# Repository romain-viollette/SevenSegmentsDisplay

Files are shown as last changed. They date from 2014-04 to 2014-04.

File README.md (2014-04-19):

SevenSegmentsDisplay
====================

description: Autonomous 3 seven-segments display powered by an Atmega328P.

author: Romain VIOLLETTE romain.viollette@gmail.com

https://github.com/romain-viollette/SevenSegmentsDisplay

http://www.oshpark.com/shared_projects/W5Fzhe9d - http://www.oshpark.com/profiles/RomainViollette

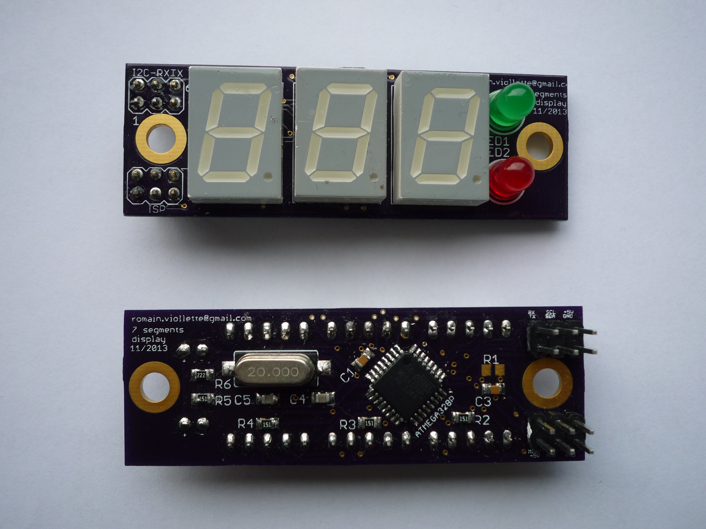
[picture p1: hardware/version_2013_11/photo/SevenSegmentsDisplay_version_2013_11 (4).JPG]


features:
  - small form factor
  - communication: Serial, I2C, SPI, (bitbanging possible if you want to) 
  - SDM components, soldering by hand is not too difficult.
  - 5 volts only
  - Arduino IDE compatible
  - programmable via ISP by default (or maybe via serial lines with a different bootloader)
  - crystal 16Mhz, 20MHz (or whatever or internal if you want to) 
  - 2 support holes for 3 mm screws

partlist: (See complete file in /version_xx/eagle/partlist.txt)
  - PCB at OSHpark.com see http://www.oshpark.com/profiles/RomainViollette
  - 3 x TDSO 5151 - Seven Segments displays with common cathode (any common cathode 7 seg display would fit)
  - 2 leds, any basic ones would fit, adapt R5 and R6 for current limiting.
  - SMD discrete parts form factor 0805:
      - C1 & C3 - 100nF - unpolarized decoupling capacitor
      - C4 & C5 - 12-22pF - unpolarized capacitor for quartz
      - ATMEGA328P-AU - TQFP32 - http://bit.ly/1gV6cmJ
      - QUARTZ - MULTICOMP HC49SM-20-30-50-60-16-ATF - http://bit.ly/1i76kLW
      - R2, R3 & R4 - 150 Ohms - current limiting resistor for 7 seg displays (adapt them to your display specs)
      - R5 & R6 - 150-2200 Ohms  - current limiting resistor for LED (adapt them to your LED specs)
      - R1 - !!!ERROR!!! - do not put anything - R1 could be used as a reset switch (I set R1 as pulldown instead of pullup)
	  
notice:
	- If you beggin in SMD, consider buying http://bit.ly/1ikUmQc and the equivalent for capacitor: you  will save a lot of money at the end.
	- R1 is wrong, see in Partlist.
	- Connectors should be placed on the same side than led display. If you want to put the connector on the other side like I did in the photos (http://bit.ly/1hbSIUK), keep in mind that the pinning is inverted.
	- There is not power regulator, nor overvoltage protection, so nerver power with more than 5V. (Maybe 3.3 could works?).
 
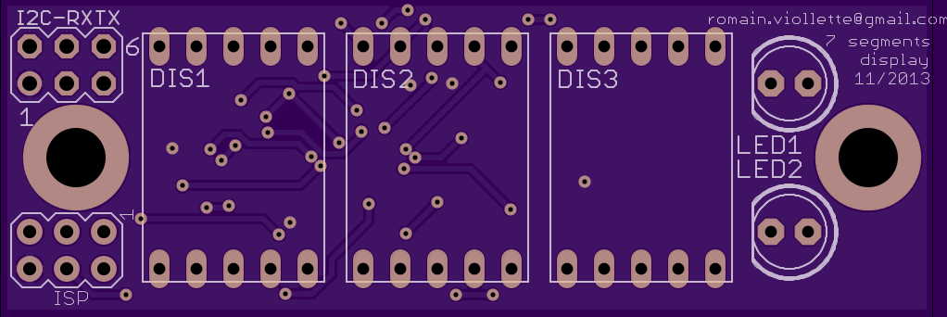
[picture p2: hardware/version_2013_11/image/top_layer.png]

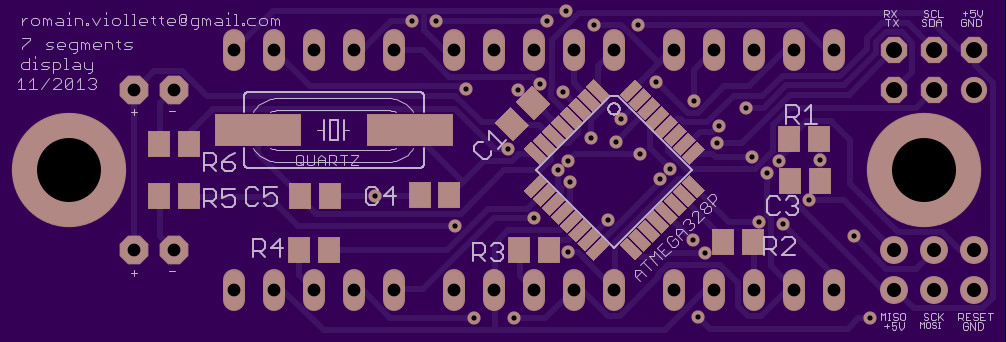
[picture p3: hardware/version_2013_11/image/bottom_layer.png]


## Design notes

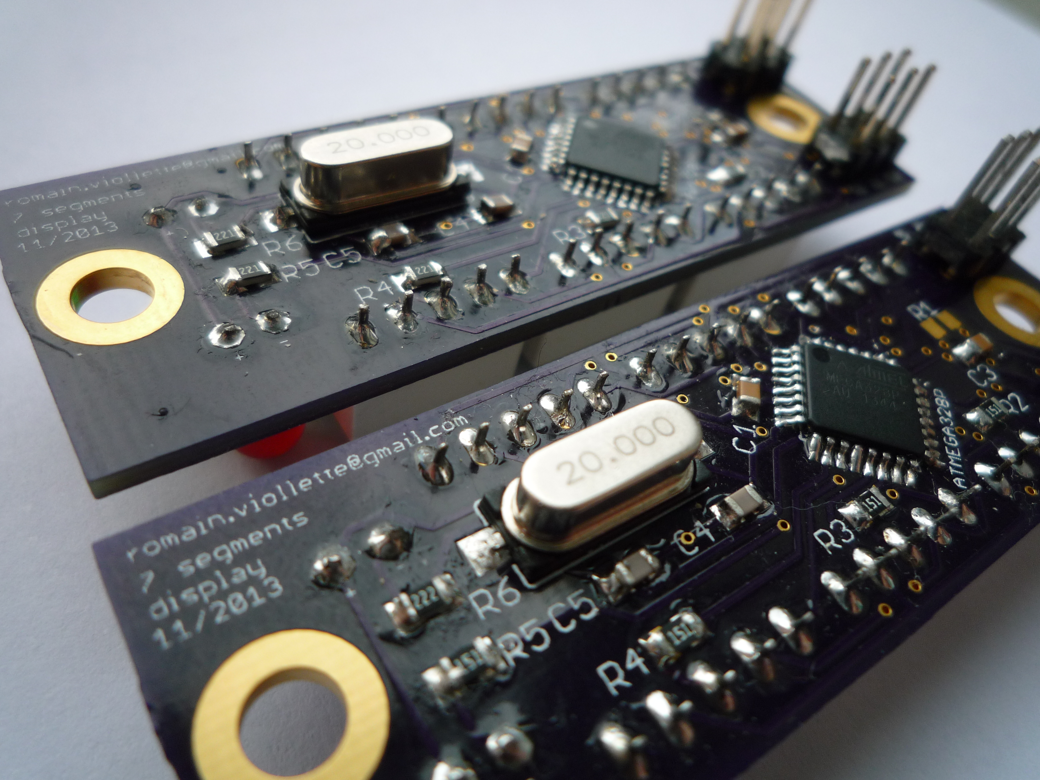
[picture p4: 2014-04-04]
hardware/version_2013_11/photo/SevenSegmentsDisplay_version_2013_11 (9).JPG

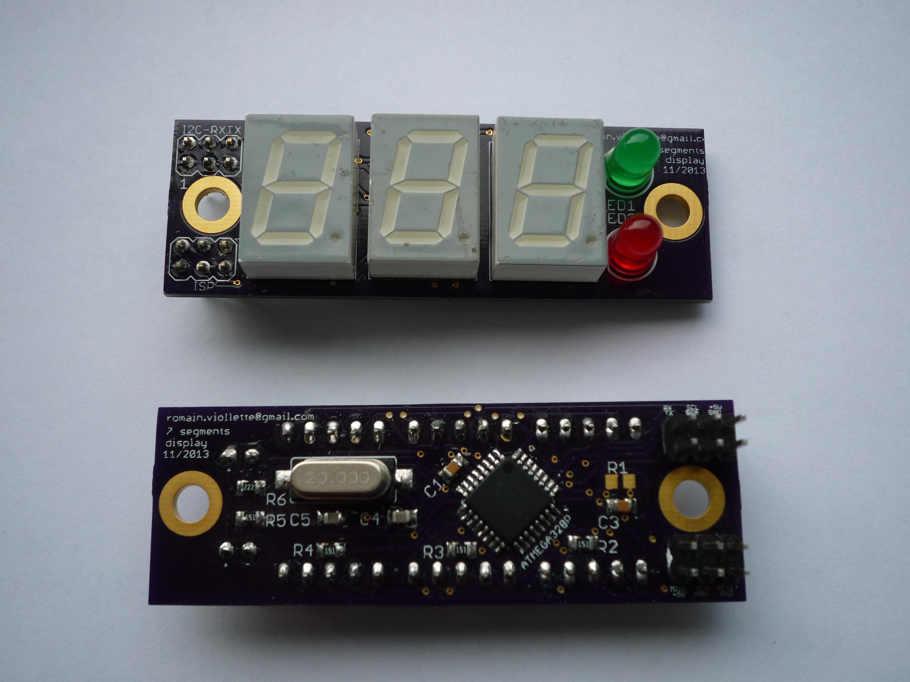
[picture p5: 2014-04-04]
hardware/version_2013_11/photo/SevenSegmentsDisplay_version_2013_11 (5).JPG

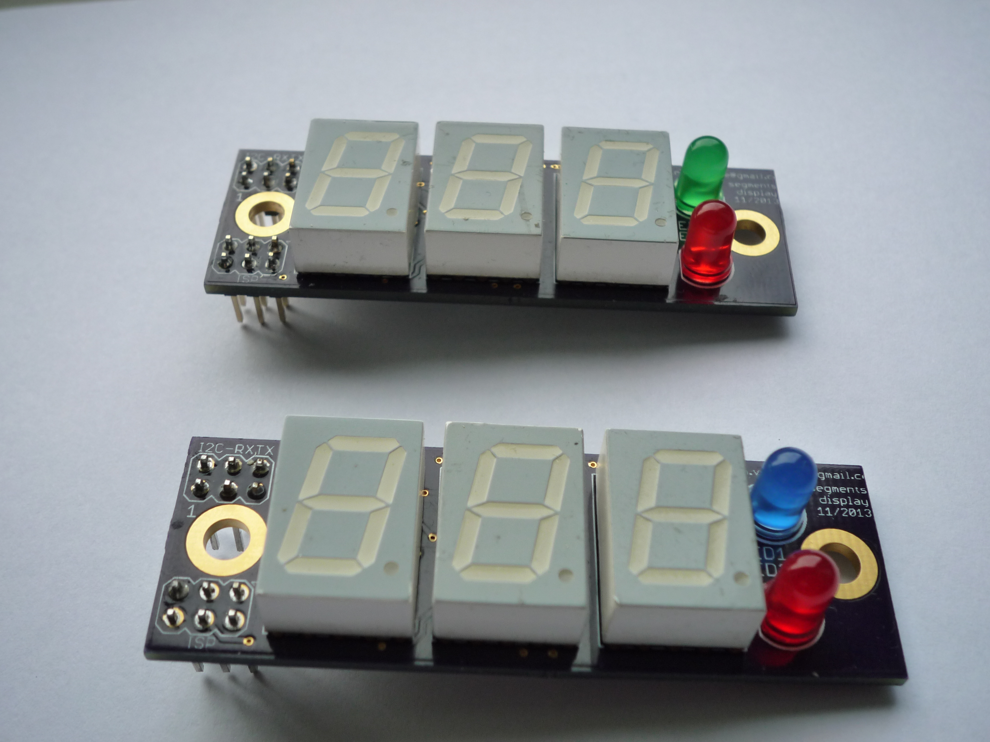
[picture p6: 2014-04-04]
hardware/version_2013_11/photo/SevenSegmentsDisplay_version_2013_11 (3).JPG

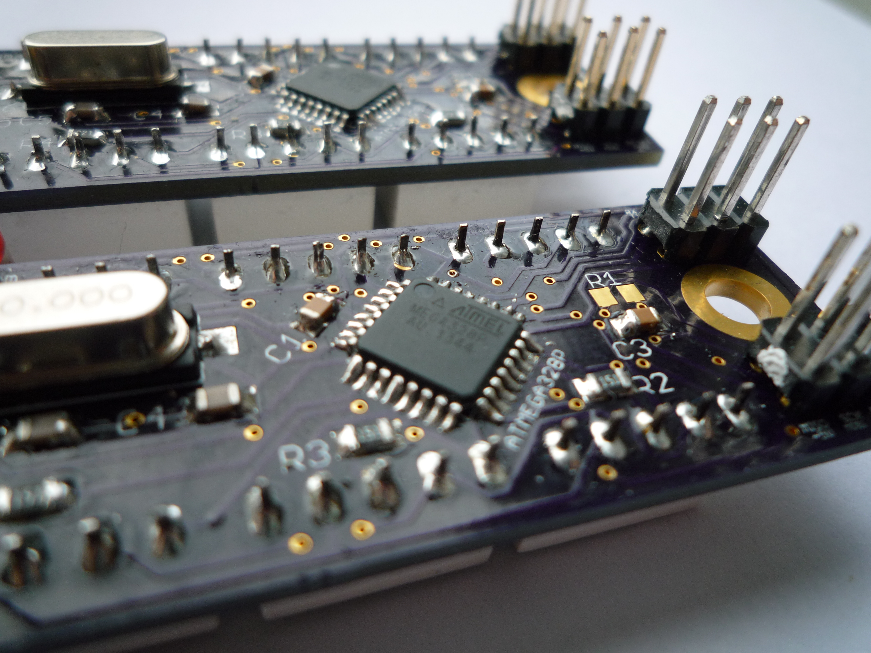
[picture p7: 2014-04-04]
hardware/version_2013_11/photo/SevenSegmentsDisplay_version_2013_11 (7).JPG

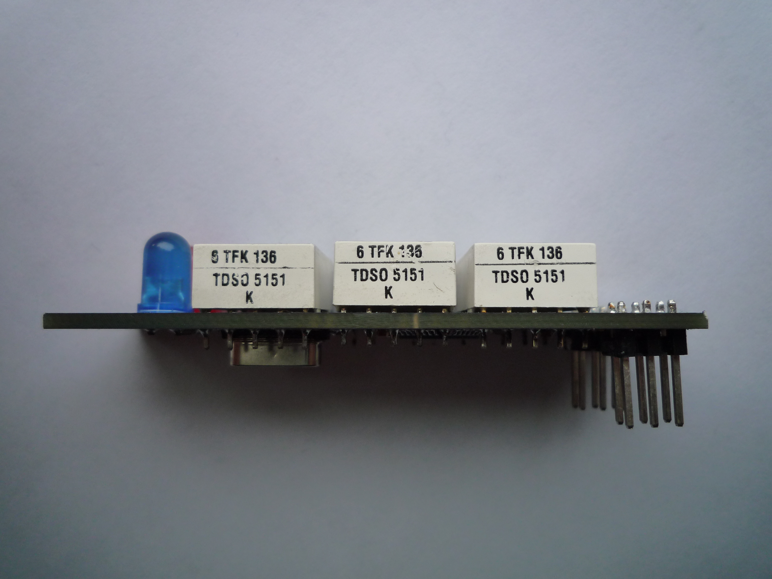
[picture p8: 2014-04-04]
hardware/version_2013_11/photo/SevenSegmentsDisplay_version_2013_11 (1).JPG

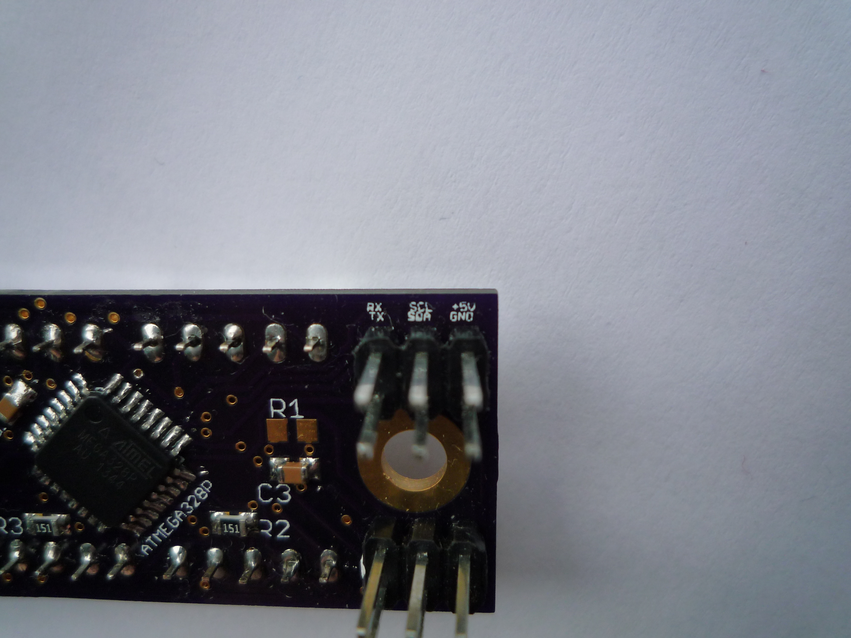
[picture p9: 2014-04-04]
hardware/version_2013_11/photo/SevenSegmentsDisplay_version_2013_11 (11).JPG

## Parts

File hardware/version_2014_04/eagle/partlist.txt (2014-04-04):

Partlist

Exported from interface.brd at 04/04/2014 16:47:50

EAGLE Version 6.1.0 Copyright (c) 1988-2012 CadSoft

Assembly variant: 

Part       Value          Package   Library    Position (inch)       Orientation

ATMEGA328P ATMEGA328P     TQFP32-08 avr-6      (0.98 0.43)           MR315
C1         100nF          C0805     rcl        (1.20992126 0.57173228) MR45
C3         100nF          C0805     rcl        (0.50362205 0.40362205) MR180
C4         12-22pF        C0805     rcl        (1.4288189 0.36661417) MR0
C5         12-22pF        C0805     rcl        (1.7284252 0.36464567) MR180
DIS1                      HDSP-M    display-hp (0.63 0.43)           R0
DIS2                      HDSP-M    display-hp (1.18 0.43)           R0
DIS3                      HDSP-M    display-hp (1.73 0.43)           R0
I2C-RXTX                  MA03-2    con-lstb   (0.18 0.68)           MR0
ISP        AVRISP-6       AVRISP    adafruit   (0.18 0.18)           MR270
LED1                      LED5MM    adafruit   (2.13 0.63)           R180
LED2                      LED5MM    adafruit   (2.13 0.23)           R180
QUARTZ     HC49SM-20      HC49UP    crystal    (1.68 0.53)           MR0
R1         10k            R0805     rcl        (0.50480315 0.50637795) MR180
R2         220            R0805     rcl        (0.67 0.25)           MR180
R3         220            R0805     rcl        (1.18 0.23)           MR0
R4         220            R0805     rcl        (1.73 0.23)           MR0
R5         220            R0805     rcl        (2.08 0.365)          MR180
R6         220            R0805     rcl        (2.08 0.495)          MR180

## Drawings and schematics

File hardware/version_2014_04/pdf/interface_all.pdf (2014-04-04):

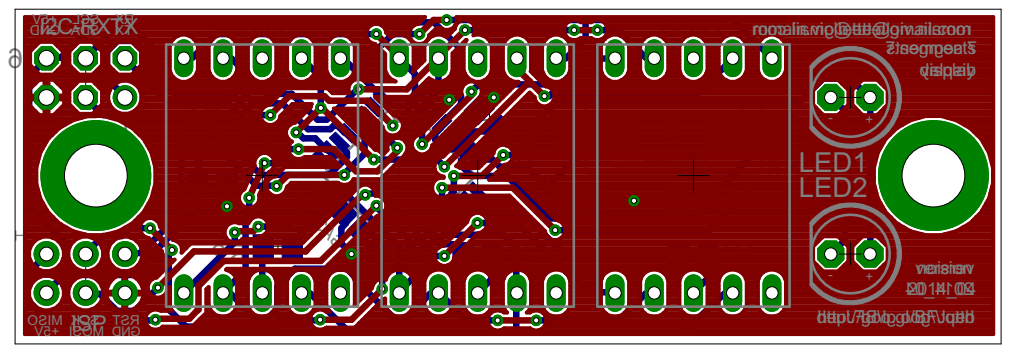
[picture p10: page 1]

3C1R1SI D 2SI D 3SI D ATMEGA328P ZTRAUQ 4C 5C C1 2R 3R 4R 5R6R 1 6I2C-RXTX ISP LED1 LED2 display romain.viollette@gmail.com 7 segments 2014_04 venrosi isornev hbttepu:/J/gFoBo/l.g.l/oBoFg/J/:upettbh 40_4102 yal psi d st ne mges 7 DNG moc.li a mg @ett ell oi v. ni a mor V5+ ADS LCS XTXR DNG TSR I SOM KCS V5+ OSI M + - + -

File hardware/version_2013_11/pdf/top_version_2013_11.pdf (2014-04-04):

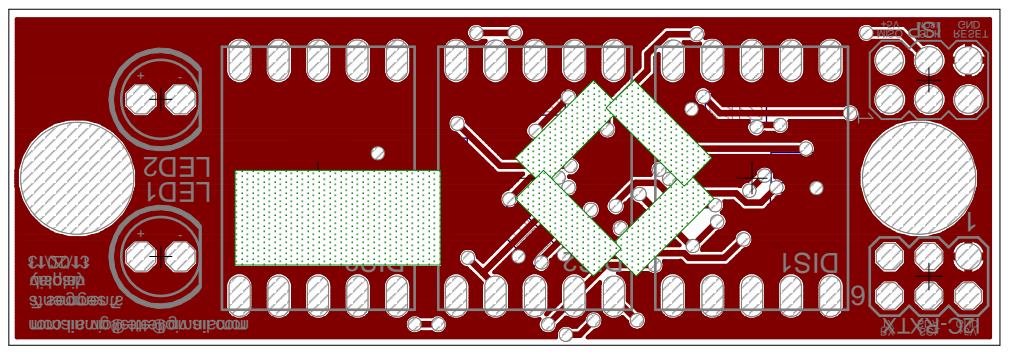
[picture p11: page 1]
11/201311/2013 display 7 segments; romain.viollette@gmail.com; GND; SDA SCL; GND RESET; MOSI SCK; +5V MISO

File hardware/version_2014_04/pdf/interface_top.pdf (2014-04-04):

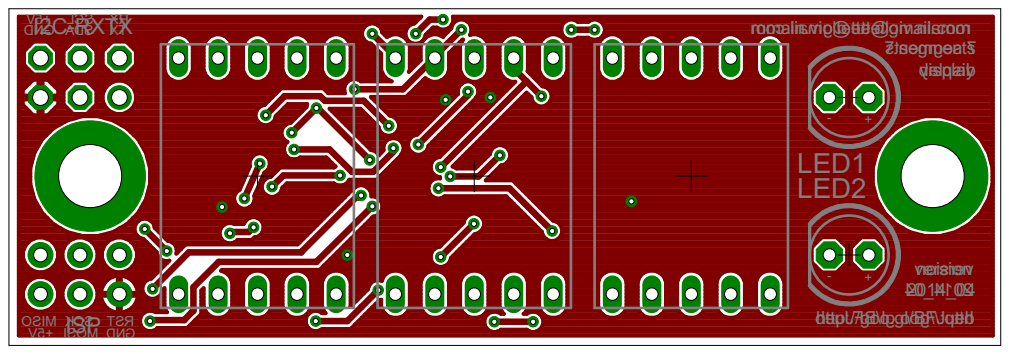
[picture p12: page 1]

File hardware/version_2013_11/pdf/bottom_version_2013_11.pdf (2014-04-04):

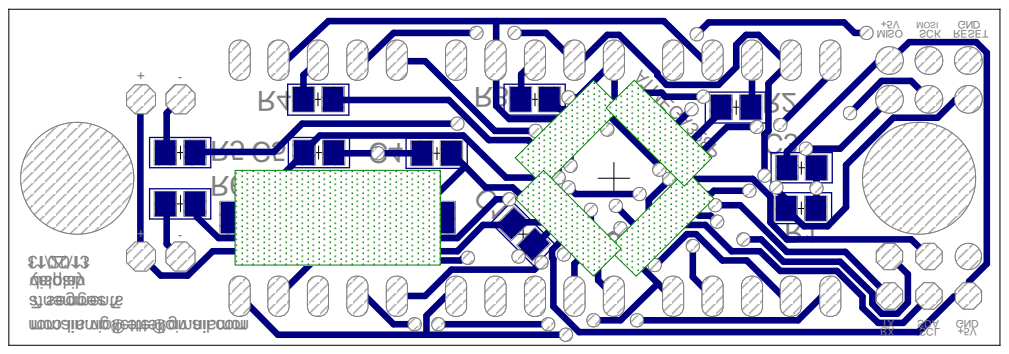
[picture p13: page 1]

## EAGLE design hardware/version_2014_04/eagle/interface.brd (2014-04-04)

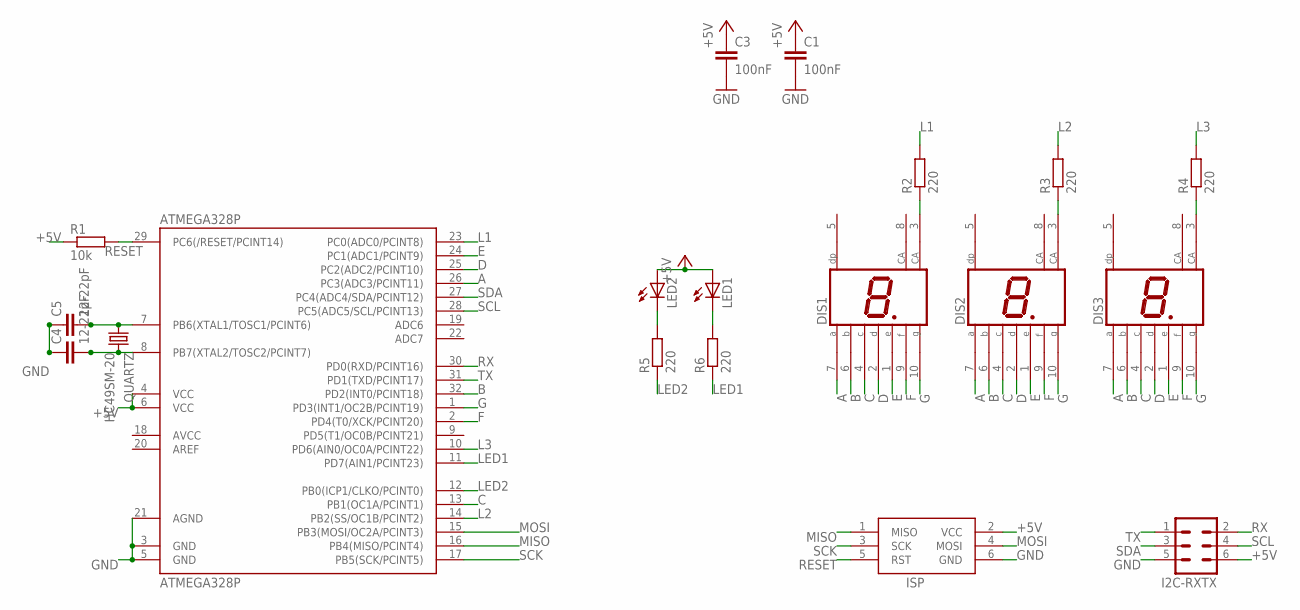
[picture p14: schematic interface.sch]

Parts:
ATMEGA328P: ATMEGA328P; TQFP32-08
C1, C3: 100nF; C0805
C4, C5: 12-22pF; C0805
DIS1, DIS2, DIS3: HD-H101; HDSP-M
I2C-RXTX: MA03-2
ISP: AVRISP-6; AVRISP
LED1, LED2: LED5MM
QUARTZ: HC49SM-20; HC49UP
R1: 10k; R0805
R2, R3, R4, R5, R6: 220; R0805

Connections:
+5V: ATMEGA328P.4 (VCC), ATMEGA328P.6 (VCC), C1.1, C3.1, I2C-RXTX.6, ISP.2 (VCC), LED1.A, LED2.A, R1.1
A: ATMEGA328P.26 (PC3(ADC3/PCINT11)), DIS1.7 (A), DIS2.7 (A), DIS3.7 (A)
B: ATMEGA328P.32 (PD2(INT0/PCINT18)), DIS1.6 (B), DIS2.6 (B), DIS3.6 (B)
C: ATMEGA328P.13 (PB1(OC1A/PCINT1)), DIS1.4 (C), DIS2.4 (C), DIS3.4 (C)
D: ATMEGA328P.25 (PC2(ADC2/PCINT10)), DIS1.2 (D), DIS2.2 (D), DIS3.2 (D)
E: ATMEGA328P.24 (PC1(ADC1/PCINT9)), DIS1.1 (E), DIS2.1 (E), DIS3.1 (E)
F: ATMEGA328P.2 (PD4(T0/XCK/PCINT20)), DIS1.9 (F), DIS2.9 (F), DIS3.9 (F)
G: ATMEGA328P.1 (PD3(INT1/OC2B/PCINT19)), DIS1.10 (G), DIS2.10 (G), DIS3.10 (G)
GND: ATMEGA328P.3 (GND), ATMEGA328P.5 (GND), ATMEGA328P.21 (AGND), C1.2, C3.2, C4.1, C5.1, I2C-RXTX.5, ISP.6 (GND)
L1: ATMEGA328P.23 (PC0(ADC0/PCINT8)), R2.2
L2: ATMEGA328P.14 (PB2(SS/OC1B/PCINT2)), R3.2
L3: ATMEGA328P.10 (PD6(AIN0/OC0A/PCINT22)), R4.2
LED1: ATMEGA328P.11 (PD7(AIN1/PCINT23)), R6.1
LED2: ATMEGA328P.12 (PB0(ICP1/CLKO/PCINT0)), R5.1
MISO: ATMEGA328P.16 (PB4(MISO/PCINT4)), ISP.1 (MISO)
MOSI: ATMEGA328P.15 (PB3(MOSI/OC2A/PCINT3)), ISP.4 (MOSI)
unnamed: ATMEGA328P.8 (PB7(XTAL2/TOSC2/PCINT7)), C4.2, QUARTZ.2
unnamed: ATMEGA328P.7 (PB6(XTAL1/TOSC1/PCINT6)), C5.2, QUARTZ.1
unnamed: DIS2.3 (CA), R3.1
unnamed: DIS3.3 (CA), R4.1
unnamed: LED2.K (C), R5.2
unnamed: DIS1.3 (CA), R2.1
unnamed: LED1.K (C), R6.2
RESET: ATMEGA328P.29 (PC6(/RESET/PCINT14)), ISP.5 (RST), R1.2
RX: ATMEGA328P.30 (PD0(RXD/PCINT16)), I2C-RXTX.2
SCK: ATMEGA328P.17 (PB5(SCK/PCINT5)), ISP.3 (SCK)
SCL: ATMEGA328P.28 (PC5(ADC5/SCL/PCINT13)), I2C-RXTX.4
SDA: ATMEGA328P.27 (PC4(ADC4/SDA/PCINT12)), I2C-RXTX.3
TX: ATMEGA328P.31 (PD1(TXD/PCINT17)), I2C-RXTX.1

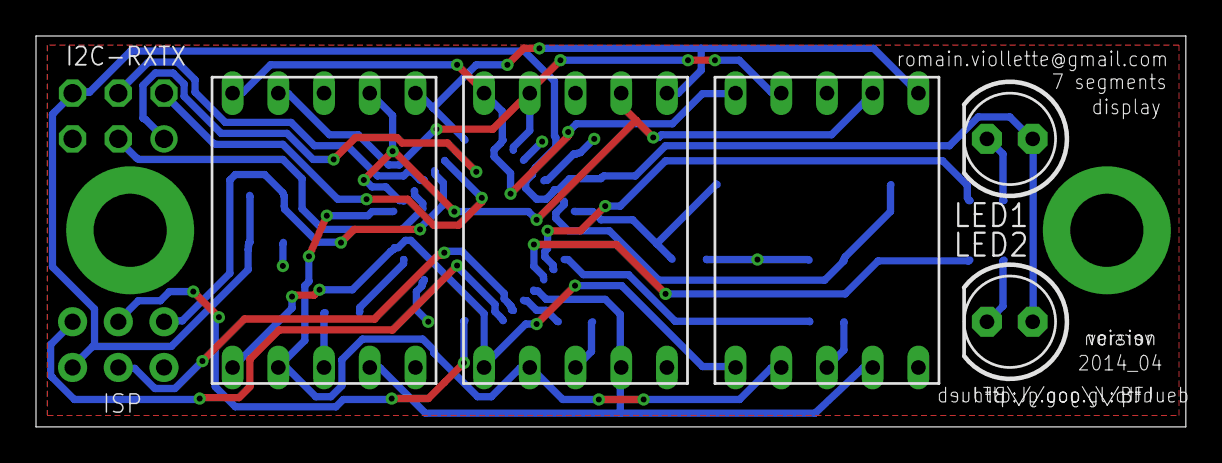
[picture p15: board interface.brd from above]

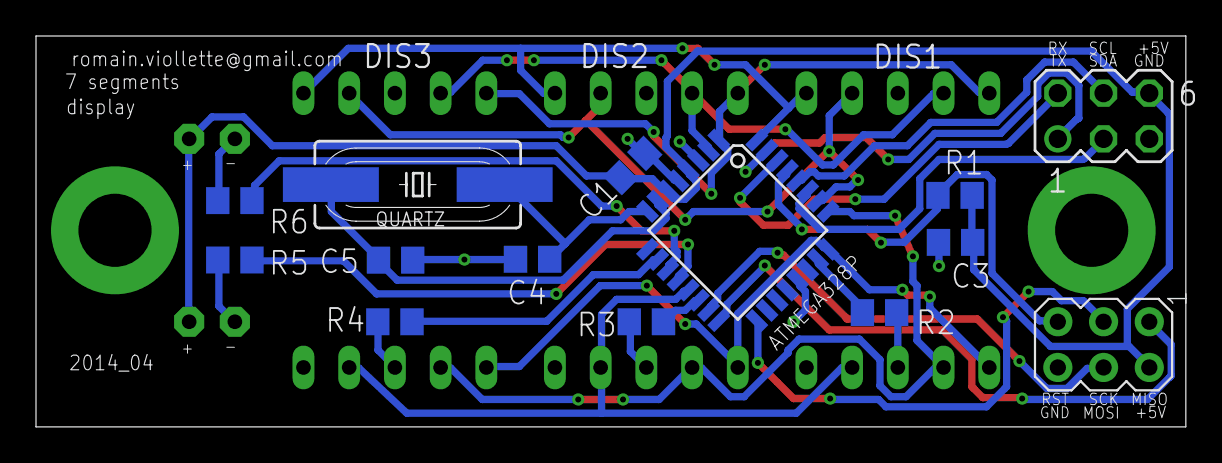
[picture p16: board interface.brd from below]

Board: 2 copper layers, 63.9 x 21.7 mm, 19 parts (14 on the bottom side), 29 nets.

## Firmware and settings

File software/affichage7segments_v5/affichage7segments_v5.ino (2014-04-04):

#include <Wire.h>

#define DEBUG       false

#define I2C_MASTER  false
#define I2C_SLAVE   true

static const uint8_t PIN_L1 =   0; //PC0  //14
static const uint8_t PIN_L2 =   2; //PB2  //10
static const uint8_t PIN_L3 =   6; //PD6; //6
static const uint8_t PIN_A =    3; //PC3; //17
static const uint8_t PIN_B =    2; //PD2; //2
static const uint8_t PIN_C =    1; //PB1; //9
static const uint8_t PIN_D =    2; //PC2; //16
static const uint8_t PIN_E =    1; //PC1; //15
static const uint8_t PIN_F =    4; //PD4; //4
static const uint8_t PIN_G =    3; //PD3; //3
static const uint8_t PIN_LED1 = 7; //PD7; //7
static const uint8_t PIN_LED2 = 0; //PB0; //8

/*

 PORT B
 MSB                              LSB
 | 7 | 6 | 5 | 4 | 3 | 2  | 1 | 0   |
 | . | . | . | . | . | L2 | C | LED2|
 
 PORT C
 MSB                            LSB
 | 7 | 6 | 5 | 4 | 3 | 2 | 1 | 0  |
 | . | . | . | . | A | D | E | L1 |
 
 PORT D
 MSB                               LSB
 | 7    | 6  | 5 | 4 | 3 | 2 | 1 | 0 |
 | LED1 | L3 | . | F | G | B | . | . |
 
 
 SEVEN SEGMENT DISPLAYS:
 ___L1__       ___L2__       ___L3__ 
 |   A   |     |   A   |     |   A   |    displayValue[x] = 0ABCDEFG;
 |F     B|     |F     B|     |F     B|
 |   G   |     |   G   |     |   G   |
 |E     C|     |E     C|     |E     C|
 |___D___|     |___D___|     |___D___|
 
 
 */

static uint8_t A, B, C , D, E, F, G;    //Active High
static uint8_t L1, L2, L3, LED1, LED2;  //Active Low

static const uint8_t DDRB_ = (1<<PIN_L2) | (1<<PIN_C) | (1<<PIN_LED2);
static const uint8_t DDRC_ = (1<<PIN_A) | (1<<PIN_D) | (1<<PIN_E) | (1<<PIN_L1);
static const uint8_t DDRD_ = (1<<PIN_LED1) | (1<<PIN_L3) | (1<<PIN_F) | (1<<PIN_G) | (1<<PIN_B);

static uint8_t displayValue[3] = {
  0, 0, 0};

static uint8_t segmentCounter = 0;
static uint8_t scrollingIndex = 0;
static uint32_t scrollingTime = 0;
static const uint32_t scrollingDuration = 1000; //ms


// Max command LENGTH
#define COMMAND_LENGTH  100
// Buffer for the incoming data
char inData[COMMAND_LENGTH];
// Buffer for the cached data
char cachedData[COMMAND_LENGTH];
// Incoming data id
static int index = 0;
// Read state of incoming datac
static boolean stringComplete = false;
static uint8_t dataLength = 0;

void setup()
{
  Serial.begin(9600);
  delay(1);
  if(DEBUG) Serial.println("\n-= Affichage 7 segments =-");

  if(I2C_MASTER) Wire.begin(1);  // join i2c bus (address optional for master)
  if(I2C_SLAVE)  
  {  
    Wire.begin(2);
    Wire.onReceive(receiveEvent); // register event
  }

  A=B=C=D=E=F=G=0;
  L1=L2=L3=LED1=LED2=1;

  for(int i=0; i< COMMAND_LENGTH; i++)
  {
    inData[i]='\0';
    cachedData[i] = '\0';
  } 

  displayValue[0] = convertAscii2Segment(' ');
  displayValue[1] = convertAscii2Segment(' ');
  displayValue[2] = convertAscii2Segment(' ');

  //settings pins as outputs:
  DDRB |= DDRB_;
  DDRC |= DDRC_;
  DDRD |= DDRD_;

}

void loop()
{
  if (stringComplete)
  {
    if(I2C_MASTER) Wire.beginTransmission(2);
    for(int i=0; i< COMMAND_LENGTH; i++)
    {
      cachedData[i] = inData[i];
      if(I2C_MASTER) Wire.write(inData[i]);  
      inData[i]='\0';
    }
    if(I2C_MASTER) Wire.endTransmission();

    // Reset the system for further
    // input of data
    stringComplete = false;

    scrollingIndex=0;
    scrollingTime = millis();
  }

  //compute display characters:
  if(dataLength > 3)
  {  
    if(millis() - scrollingTime > scrollingDuration)
    {
      scrollingTime = millis();
      if(dataLength  <= scrollingIndex  )
        scrollingIndex = 0;
      else
        scrollingIndex++;
    }
  }

  displayValue[0] = convertAscii2Segment(cachedData[0+scrollingIndex]);
  displayValue[1] = convertAscii2Segment(cachedData[1+scrollingIndex]);
  displayValue[2] = convertAscii2Segment(cachedData[2+scrollingIndex]);

  if(DEBUG) {
    Serial.write(cachedData[0]);
    Serial.write(cachedData[1]);
    Serial.write(cachedData[2]);
    Serial.println();

    Serial.print(displayValue[0],BIN); 
    Serial.print(' ');
    Serial.print(displayValue[1],BIN); 
    Serial.print(' ');
    Serial.print(displayValue[2],BIN); 
    Serial.println();
  }


  //prepare display outputs variables;
  A= (segmentCounter==6)?LOW:HIGH;
  B= (segmentCounter==5)?LOW:HIGH;
  C= (segmentCounter==4)?LOW:HIGH;
  D= (segmentCounter==3)?LOW:HIGH;
  E= (segmentCounter==2)?LOW:HIGH;
  F= (segmentCounter==1)?LOW:HIGH;
  G= (segmentCounter==0)?LOW:HIGH;

  L1= (displayValue[0]&(1<<segmentCounter))?HIGH:LOW;
  L2= (displayValue[1]&(1<<segmentCounter))?HIGH:LOW;
  L3= (displayValue[2]&(1<<segmentCounter))?HIGH:LOW;

  //write outputs register:
  PORTB = (PORTB & ~DDRB_) | (L2<<PIN_L2) | (C<<PIN_C) | (LED2<<PIN_LED2);
  PORTC = (PORTC & ~DDRC_) | (A<<PIN_A) | (D<<PIN_D) | (E<<PIN_E) | (L1<<PIN_L1);
  PORTD = (PORTD & ~DDRD_) | (LED1<<PIN_LED1) | (L3<<PIN_L3) | (F<<PIN_F) | (G<<PIN_G) | (B<<PIN_B); 


  segmentCounter++;
  if(segmentCounter >= 7)
    segmentCounter=0;

  receiveEvent(0);
  //delayMicroseconds(1000);
}

void serialEvent()
{
  // Read while we have data
  while (Serial.available() && stringComplete == false)
  {
    if(index>=COMMAND_LENGTH)
    {
      Serial.flush();
      stringComplete =true;
      index = 0;
      return;
    }
    // Read a character
    char inChar = Serial.read();

    // Check for termination character
    if (inChar == '\n' || inChar == '\r')
    {
      // Reset the index
      dataLength = index;
      index = 0;
      Serial.flush();
      // Set completion of read to true
      stringComplete = true; 
      return;
    }

    // Store it in char array
    inData[index] = inChar;
    // Increment where to write next
    index++;
  }
}

void receiveEvent(int howMany)
{
  while(Wire.available() && stringComplete == false) // loop through all but the last
  {

    if(index>=COMMAND_LENGTH)
    {
      Wire.flush();
      stringComplete =true;
      index = 0;
      return;
    }
    // Read a character
    char inChar = Wire.read();
    Serial.write(inChar);

    // Check for termination character
    if (inChar == '\n' || inChar == '\r')
    {
      // Reset the index
      dataLength = index;
      index = 0;
      Wire.flush();
      // Set completion of read to true
      stringComplete = true; 
      return;
    }

    // Store it in char array
    inData[index] = inChar;
    // Increment where to write next
    index++;
  }
}


uint8_t convertAscii2Segment(char ascii)
{
  switch(ascii)
  {
  case '0' : 
    return 0b01111110;
  case '1' : 
    return 0b00110000;
  case '2' : 
    return 0b01101101;
  case '3' : 
    return 0b01111001;
  case '4' : 
    return 0b00110011;
  case '5' : 
    return 0b01011011;
  case '6' : 
    return 0b01011111;
  case '7' : 
    return 0b01110000;
  case '8' : 
    return 0b01111111;
  case '9' : 
    return 0b01110011;

  case 'a' :
  case 'A' : 
    return 0b01110111;

  case 'b' :
  case 'B' : 
    return 0b00011111;

  case 'c' : 
    return 0b00001101;
  case 'C' : 
    return 0b01001110;

  case 'd' :
  case 'D' : 
    return 0b00111101;

  case 'e' :
  case 'E' : 
    return 0b01001111;

  case 'f' :
  case 'F' : 
    return 0b01000111;

  case 'g' :
  case 'G' : 
    return 0b01011110;

  case 'h' : 
    return 0b00010111;
  case 'H' : 
    return 0b00110111;

  case 'i' :
  case 'I' : 
    return 0b00000110;

  case 'j' :
  case 'J' : 
    return 0b00111100;

  case 'k' :
  case 'K' : 
    return 0b01010111;

  case 'l' : 
    return 0b00000110;
  case 'L' : 
    return 0b00001110;

  case 'm' : 
    return 0b00010101;
  case 'M' : 
    return 0b01110110;

  case 'n' :
    return 0b00010101;
  case 'N' : 
    return 0b01110110;

  case 'o' : 
    return 0b00011101;
  case 'O' : 
    return 0b01111110;

  case 'p' :
  case 'P' : 
    return 0b01100111;

  case 'q' :
  case 'Q' : 
    return 0b01110011;

  case 'r' :
  case 'R' : 
    return 0b00000101;

  case 's' :
  case 'S' : 
    return 0b01011011;

  case 't' :
  case 'T' : 
    return 0b00001111;

  case 'u' : 
    return 0b00011100;
  case 'U' : 
    return 0b00111110;

  case 'v' : 
    return 0b00011100;
  case 'V' : 
    return 0b00111110;

  case 'w' : 
    return 0b00011100;
  case 'W' : 
    return 0b00111110;

  case 'x' :
  case 'X' : 
    return 0b00100101;

  case 'y' :
  case 'Y' : 
    return 0b0111011;

  case 'z' :
  case 'Z' : 
    return 0b01101100;


  case '-' : 
    return 0b00000001;
  case '_' : 
    return 0b00001000;
  case '=' : 
    return 0b00001001;
  case '"' : 
    return 0b00100010;
  case '\'': 
    return 0b00100000;
  case '`' : 
    return 0b00000010;
  case '.' :
  case ',' : 
    return 0b00010000;
  case ' ' : 
    return 0b00000000;
  case '^' : 
    return 0b01000000;
  case '|' : 
    return 0b00000100;
  case '\0':
    return 0b00000000;

  default:   
    return 0b00001000; //'_'
  } 
}

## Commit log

2014-04-04 first commit - hardware version 2013_11
    [interface.brd, interface.sch]
2014-04-04 added raw software files
    arduino IDE >= 1.0
2014-04-04 added top and bottom pcb image for version 2013_11
2014-04-04 folder structure changed
    [interface.brd, interface.sch]
2014-04-04 version 2013_11 was in fact newer, now corrected
    [interface.brd, interface.sch]
2014-04-04 correction of resistor R1 mistake
    [interface.brd, interface.sch]
2014-04-04 changing placing side of ISP connector
    [interface.brd, interface.sch]
2014-04-04 mirrored RXTX connector
    [interface.brd, interface.sch]
